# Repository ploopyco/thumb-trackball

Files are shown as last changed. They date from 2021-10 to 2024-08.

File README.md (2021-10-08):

# The Ploopy Thumb Trackball

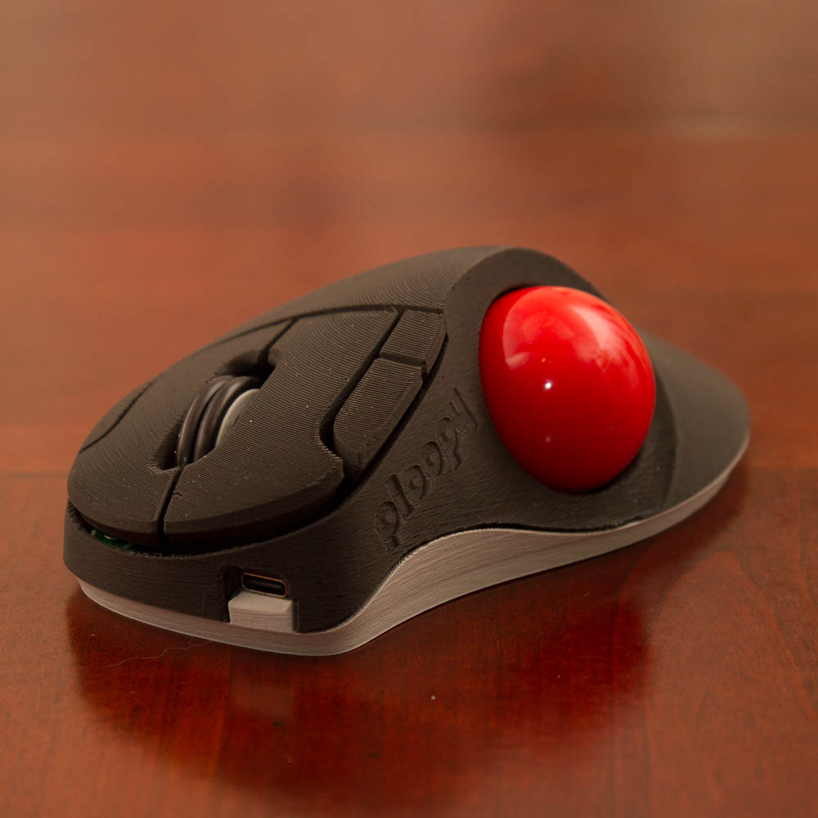
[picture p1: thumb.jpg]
The Ploopy Thumb Trackball


By some stroke of luck, you've made your way here. The Ploopy Thumb Trackball. Your life will never be the same.

This repository contains all of the design and production files necessary to make a Ploopy Thumb Trackball. We've also included some kick-ass documentation in the Wiki on how to get it made, assemble it, and program it.

What are you waiting for? Your new life awaits.

## QMK?!

Kits bought from the [Ploopy store](https://ploopy.co/product-category/trackball/thumb/) come with QMK preloaded. Check out the Wiki for instructions on how to load new firmware onto your device. (It's super easy!)

The firmware hex file that ships with all Nanos is included in this repository as well, as `ploopyco_trackball_thumb_rev1_001_via.hex`.

## Under what license is this released?

As per QMK's licensing requirements, the firmware for the Ploopy Thumb Trackball is released under GPLv3. Hardware design files, including electronics and mechanical files, are released under OHL CERN v2-S. Check the `LICENSE` file for full license text.

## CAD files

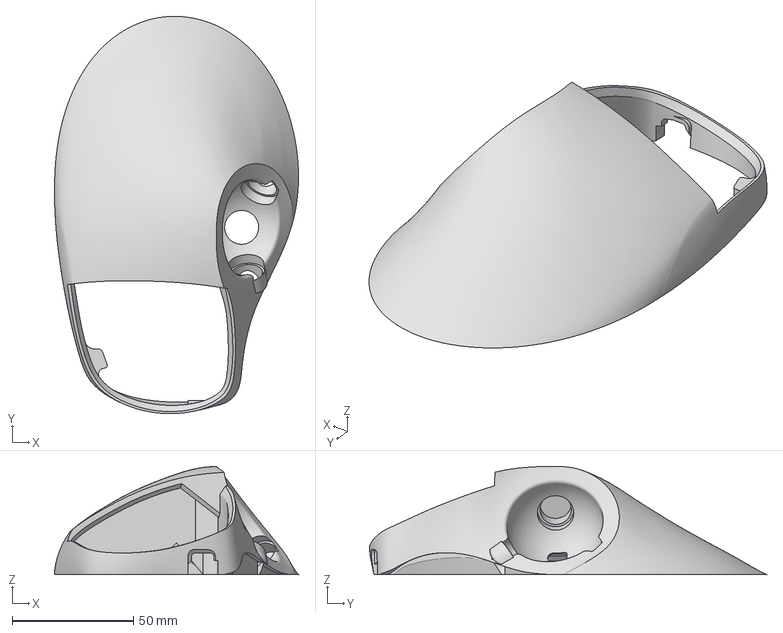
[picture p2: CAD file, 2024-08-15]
hardware/mechanicals-btu-mod/ploopy-thumb-btus-v1.3mf
100.7 x 164.0 x 44.7 mm

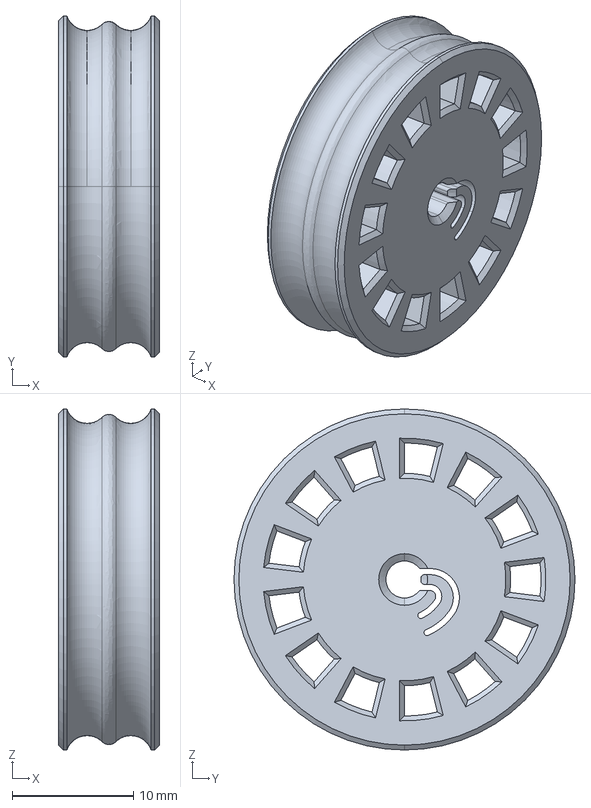
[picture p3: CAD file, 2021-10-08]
hardware/mechanicals/STEPs/ScrollWheel.STEP
8.30 x 28.1 x 28.1 mm

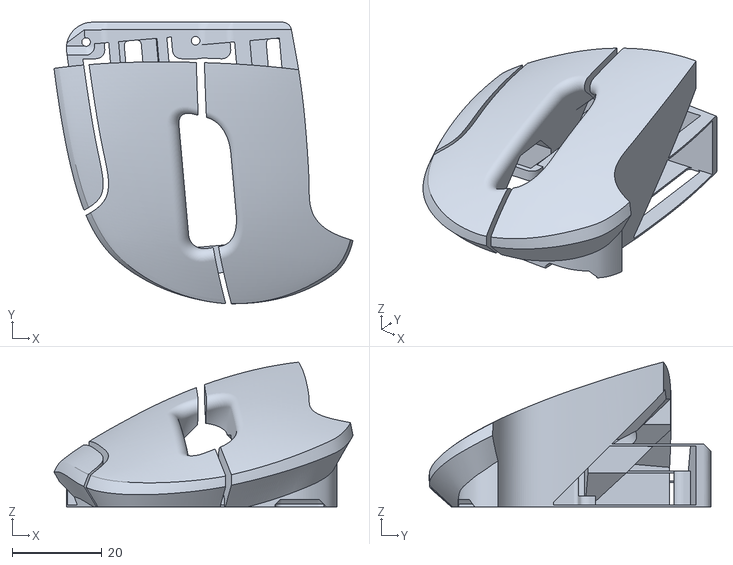
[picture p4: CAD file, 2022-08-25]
hardware/mechanicals/STLs/BigButtons.STL
66.6 x 62.7 x 32.3

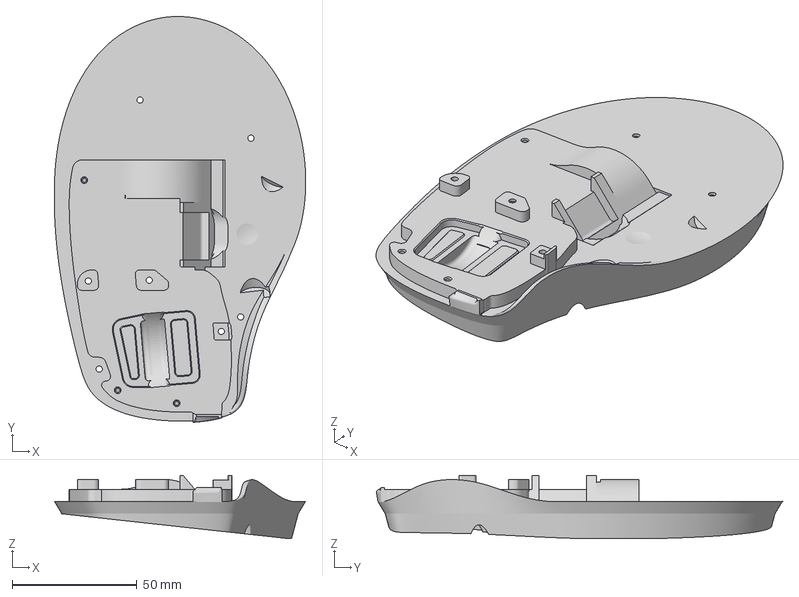
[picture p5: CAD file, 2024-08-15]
hardware/mechanicals-btu-mod/thumb-btu-base.3mf
100.7 x 162.6 x 25.4 mm

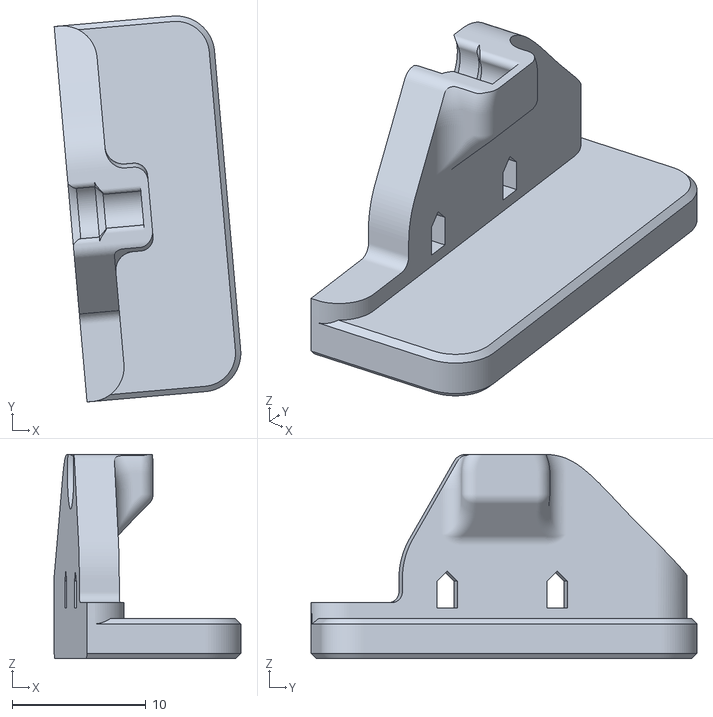
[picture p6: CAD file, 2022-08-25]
hardware/mechanicals/STLs/ScrollWheelFixedMount.STL
14.0 x 28.9 x 15.3

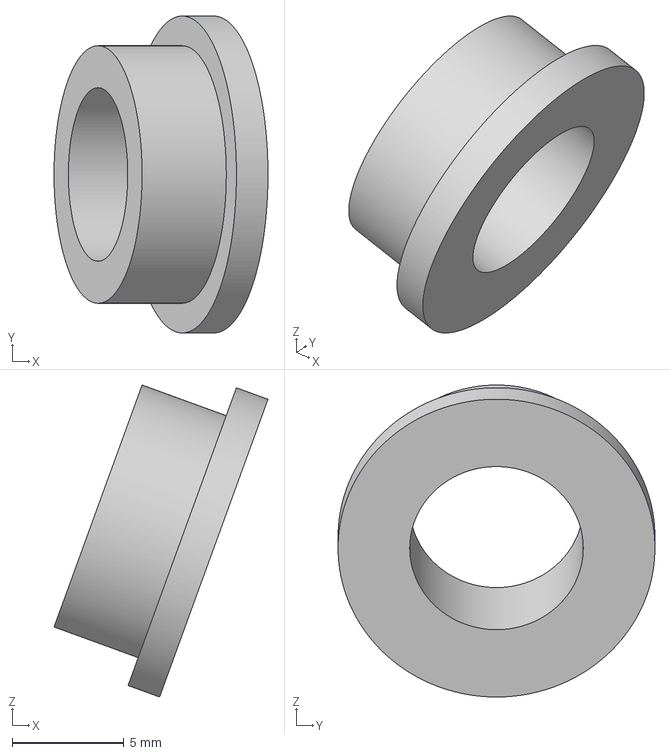
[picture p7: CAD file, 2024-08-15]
hardware/mechanicals-btu-mod/btu-sleeve.3mf
9.55 x 14.1 x 13.9 mm

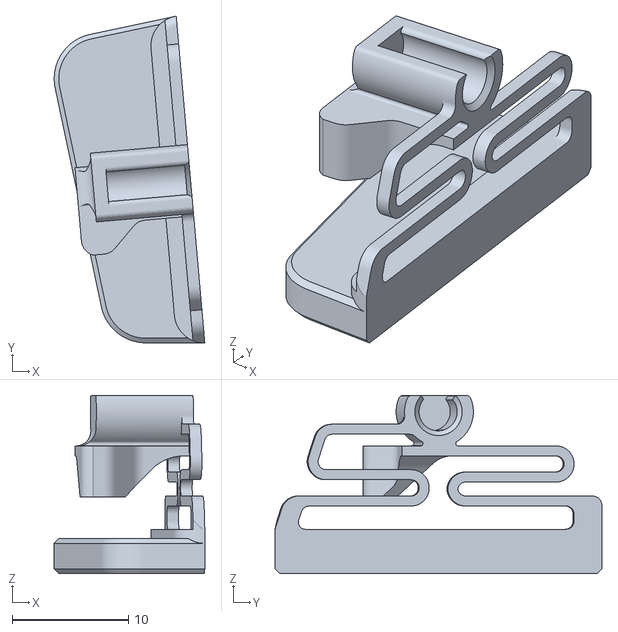
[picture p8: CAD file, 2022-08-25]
hardware/mechanicals/STLs/ScrollWheelSpring.STL
12.9 x 28.1 x 15.3

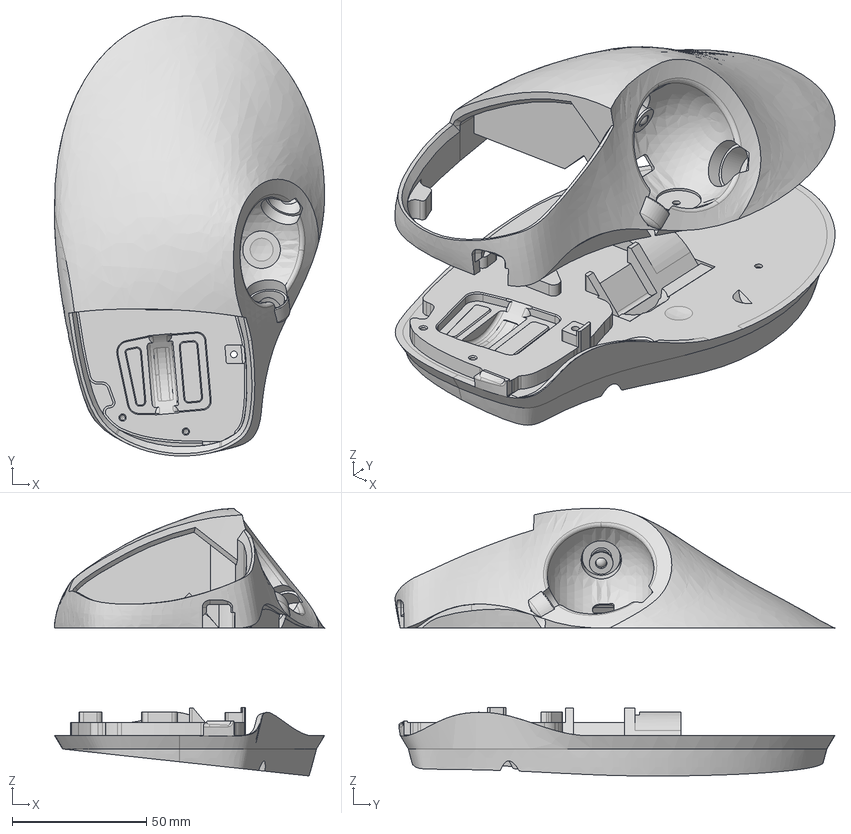
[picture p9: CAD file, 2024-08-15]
hardware/mechanicals-btu-mod/ThumbBodyParts-BTU v12.step
100.8 x 164.0 x 99.7 mm
BTU
btusleeve

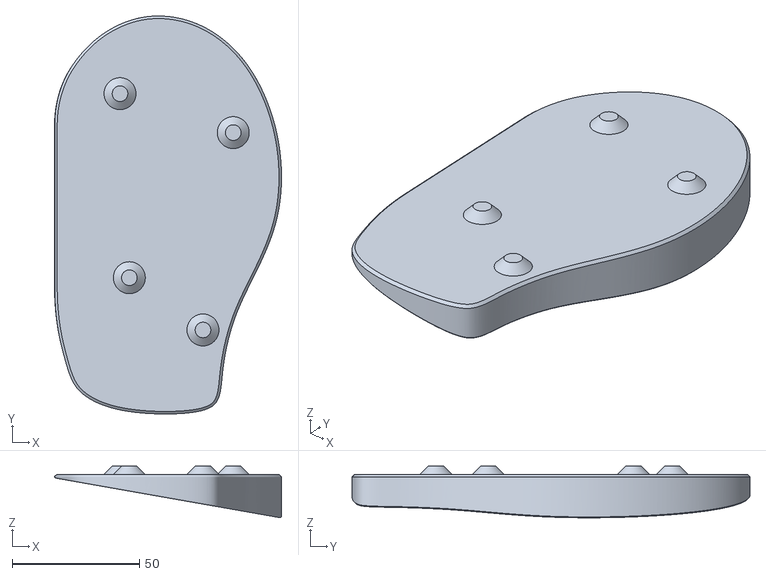
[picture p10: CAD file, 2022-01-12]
hardware/mechanicals/STLs/Wedge.STL
89.1 x 156.1 x 20.2

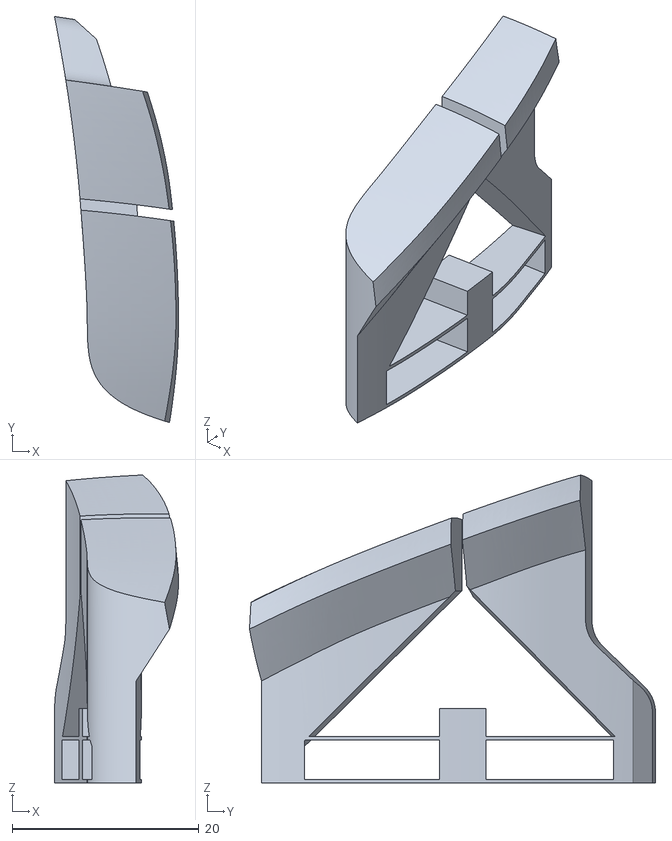
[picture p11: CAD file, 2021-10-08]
hardware/mechanicals/STLs/LittleButtons.STL
13.3 x 43.5 x 33.0

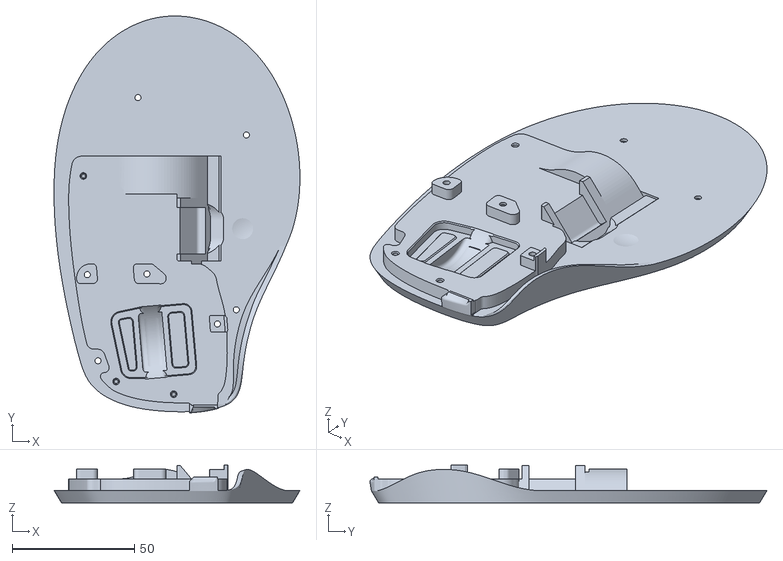
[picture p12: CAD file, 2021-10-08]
hardware/mechanicals/STLs/Bottom-NoLogo.STL
100.7 x 162.6 x 15.4

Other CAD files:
hardware/mechanicals/STLs/Top-NoLogo.STL
hardware/mechanicals/STLs/ScrollWheel.stl

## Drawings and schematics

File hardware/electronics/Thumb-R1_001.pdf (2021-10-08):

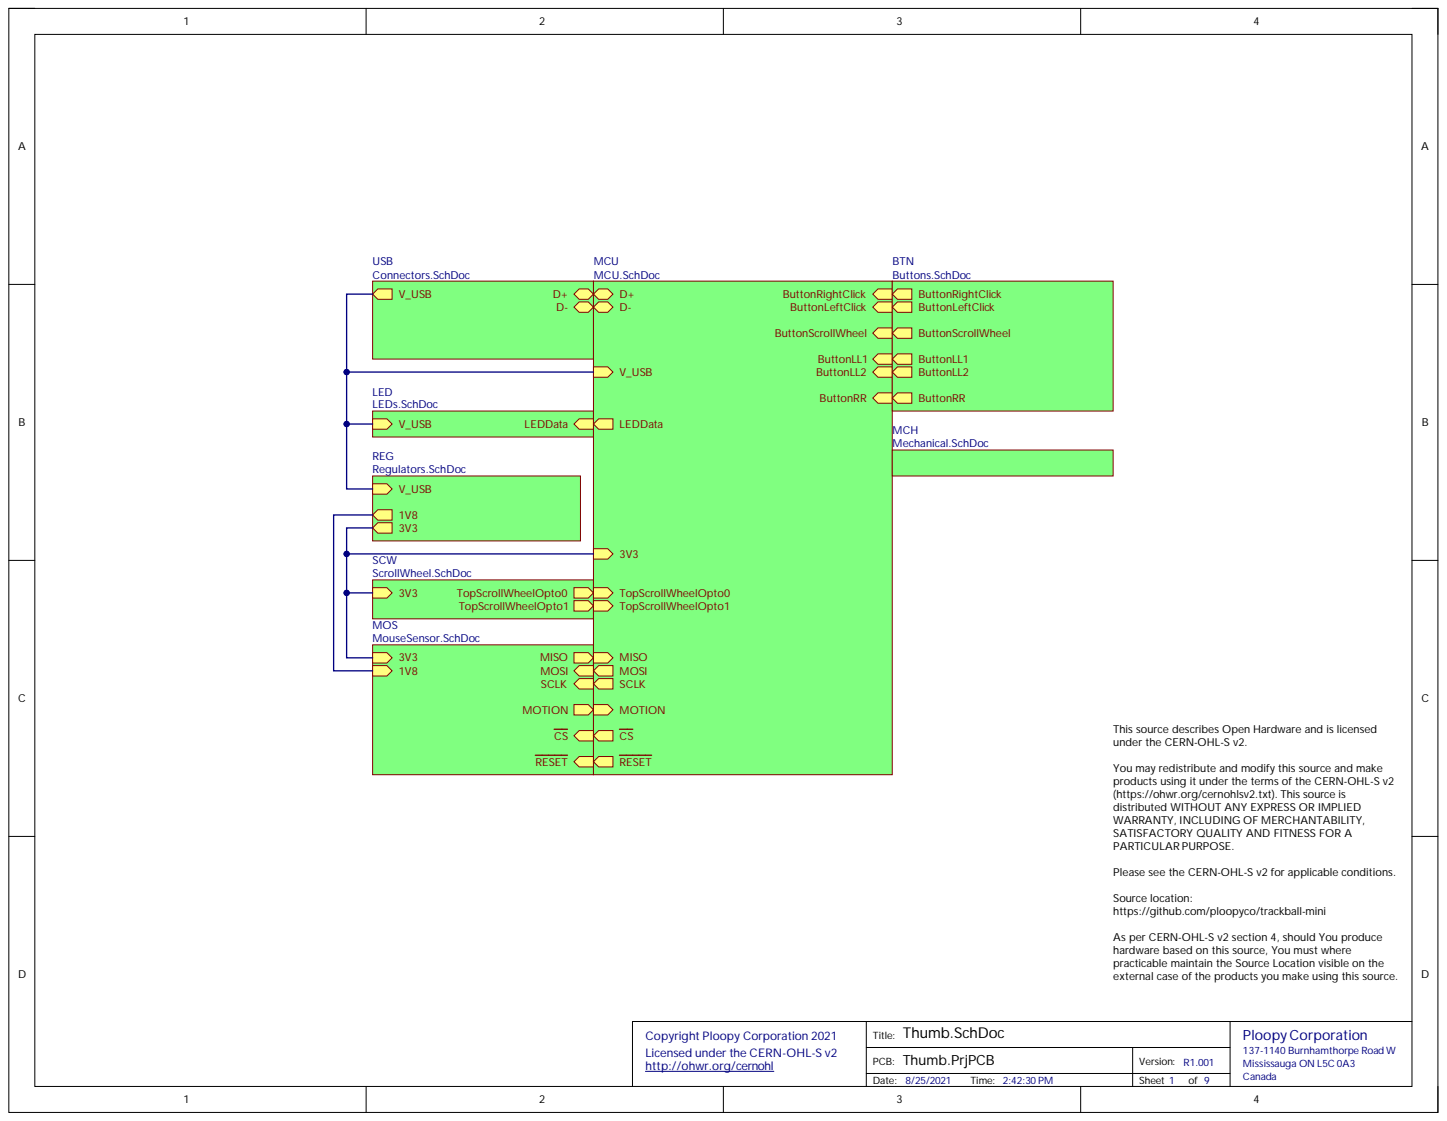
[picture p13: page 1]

This source describes Open Hardware and is licensed
under the CERN-OHL-S v2.

You may redistribute and modify this source and make
products using it under the terms of the CERN-OHL-S v2
(https://ohwr.org/cernohlsv2.txt). This source is
distributed WITHOUT ANY EXPRESS OR IMPLIED
WARRANTY, INCLUDING OF MERCHANTABILITY,
SATISFACTORY QUALITY AND FITNESS FOR A
PARTICULAR PURPOSE.

Please see the CERN-OHL-S v2 for applicable conditions.

Source location:
https://github.com/ploopyco/trackball-mini

As per CERN-OHL-S v2 section 4, should You produce
hardware based on this source, You must where
practicable maintain the Source Location visible on the
external case of the products you make using this source.

Copyright Ploopy Corporation 2021
Licensed under the CERN-OHL-S v2
http://ohwr.org/cernohl

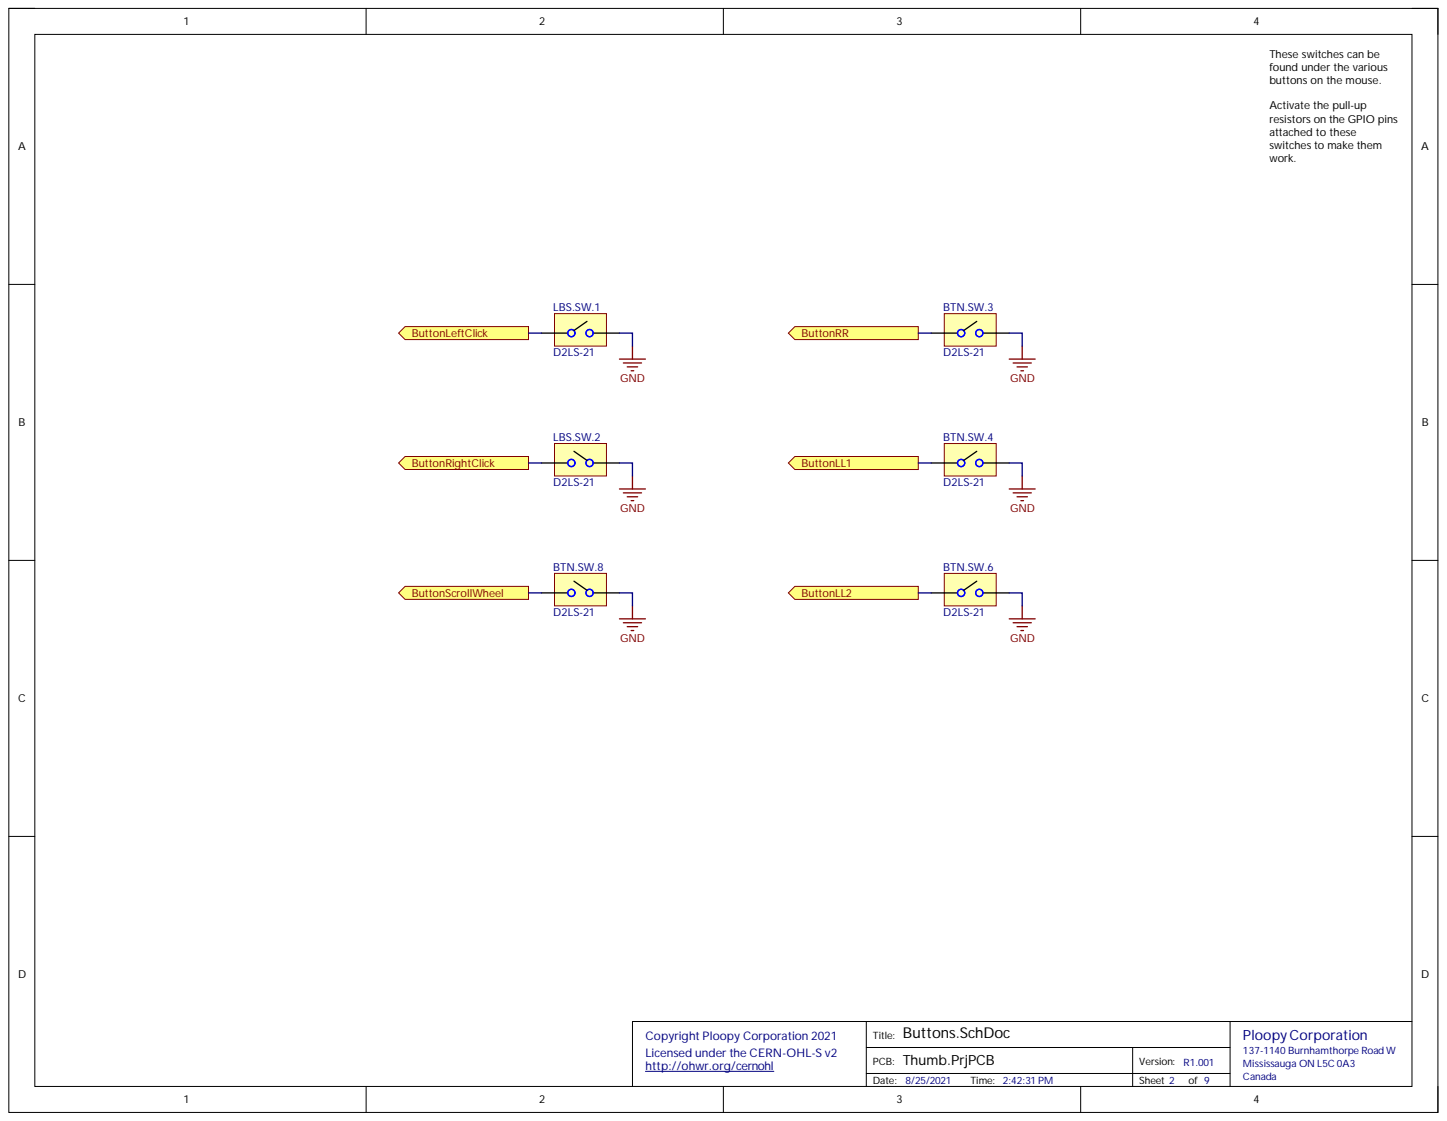
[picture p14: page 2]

These switches can be
found under the various
buttons on the mouse.

Activate the pull-up
resistors on the GPIO pins
attached to these
switches to make them
work.

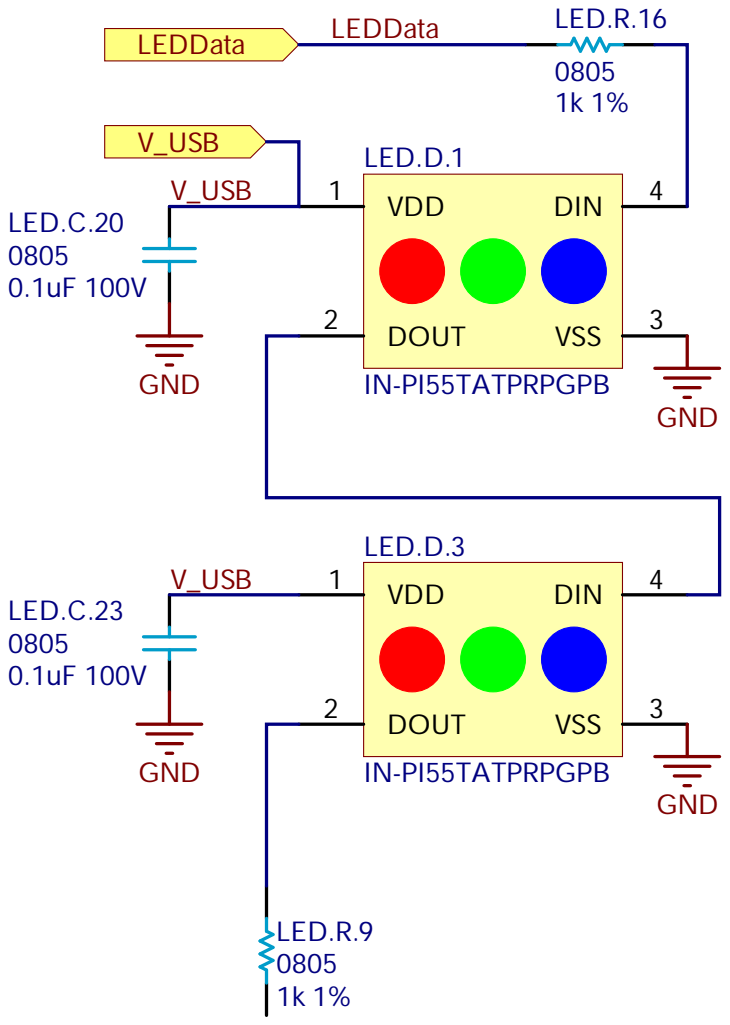
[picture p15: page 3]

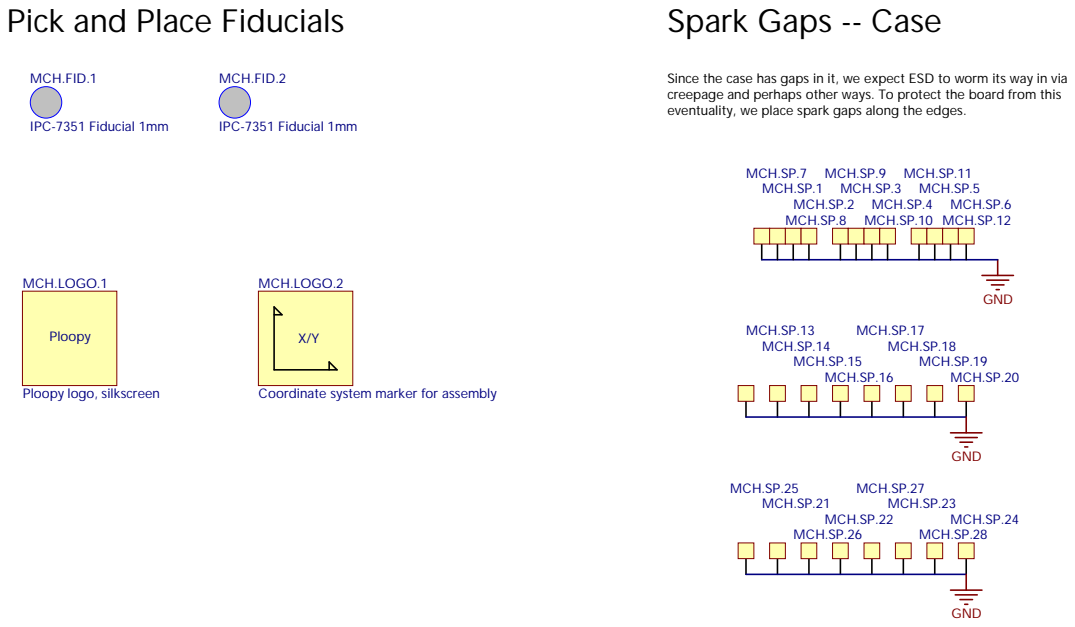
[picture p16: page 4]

Pick and Place Fiducials

Spark Gaps -- Case MCH.SP.7 MCH.SP.1 MCH.SP.8 MCH.SP.2 MCH.SP.9 MCH.SP.3 MCH.SP.10 MCH.SP.4 MCH.SP.1

Since the case has gap
creepage and perhap
eventuality, we place s

s other ways. To protect the board from this
park gap

pect ESD to worm its way in via

Coordinate system marker for assem

Cop
Licensed under the CE
http

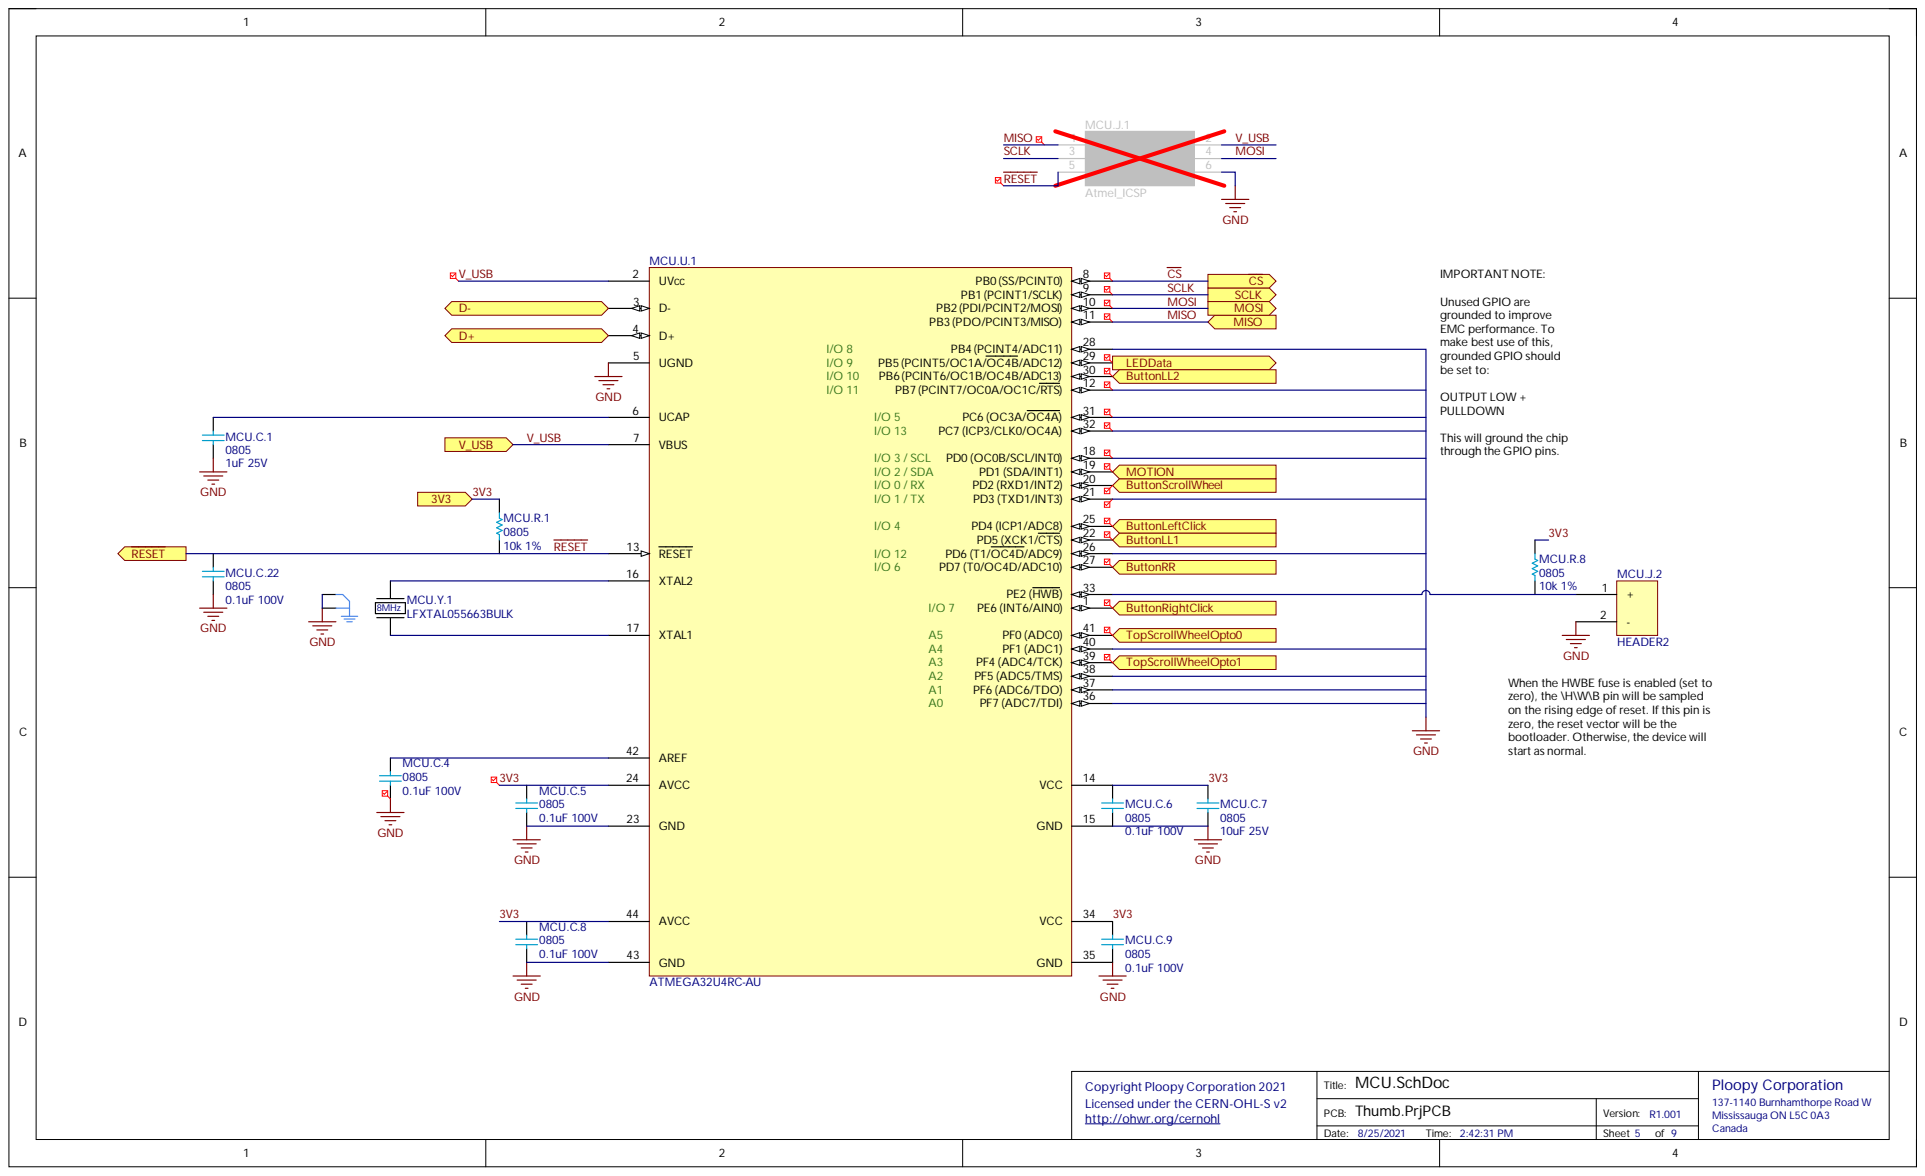
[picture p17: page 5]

performance.
best use of thi
GPI

C opy righ t Plo opy C o rpo ratio n 2 0 2 1 Lice n sed u nde r t h e CERN -O HL-S v 2 h t tp://o hwr.o rg/ce r n o h l | T i t le: MCU.SchDo c | Ploop y Corporation 137-1140 Burnha m tho rpe Ro ad W M i ss i ssauga ON L5C 0A 3 C anada

Thum b.PrjPC B P C B : | Vers i o n : R1.001

D a te: 8/25/2021 T i me: 2:42:31 P M | Sheet 5 o f 9

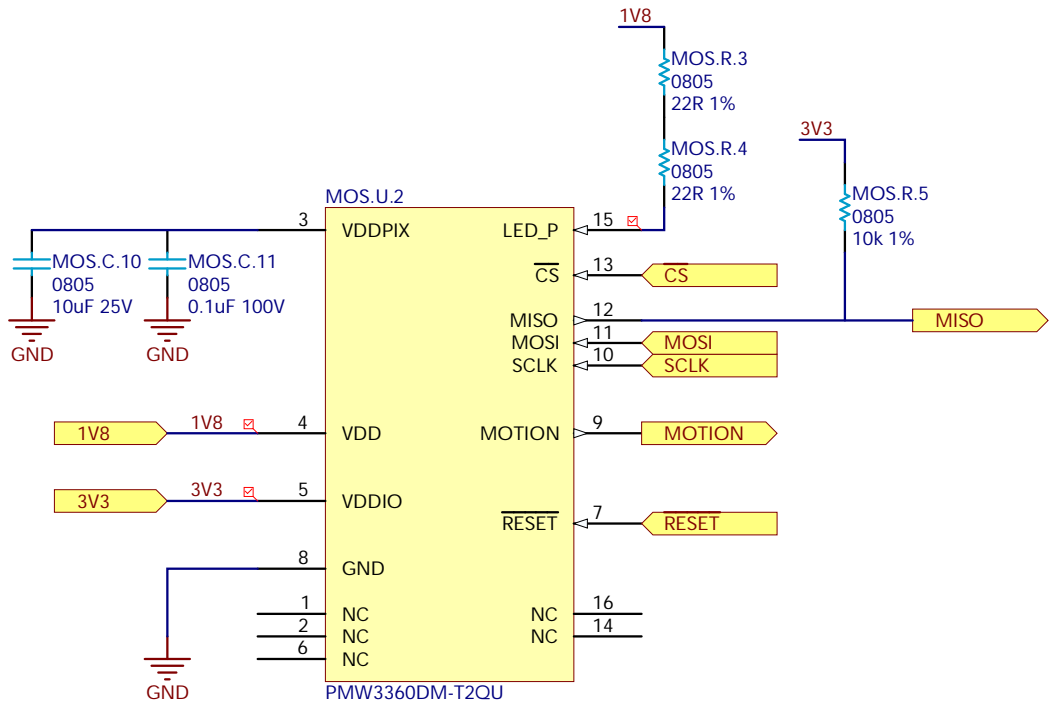
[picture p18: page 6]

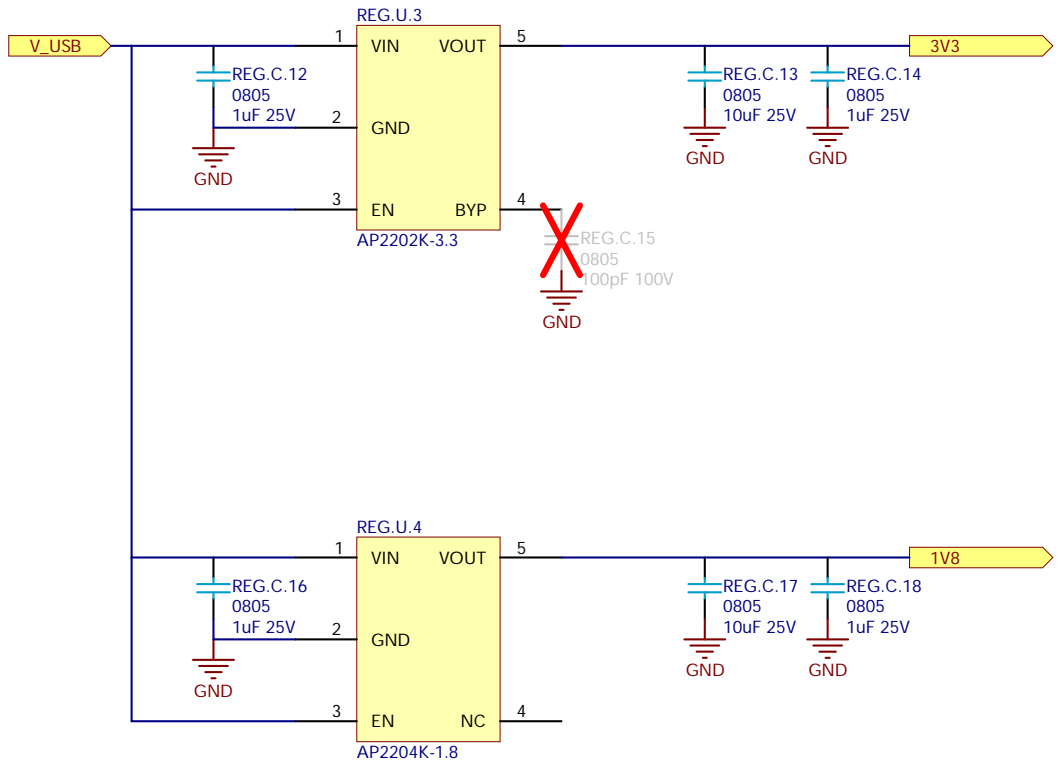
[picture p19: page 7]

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
## Ploopy

## Corporati

o

n

Mississauga ON

L5C 0A3

Sc

## rollWheel.SchDoc

R1.

8/25/202

1 | 2:42:31

P

M

Titl

e

:

Date

:

Versi

o

n

:

Ti

m

e

: | She e

t

o

f

PCB

:

## Thumb.Prj

P

C

B

Cop

yri

ght Ploop

y Corporation 2021
137-1140

Burnhamthorpe Ro

ad

W

Cana

d

a

Licensed under the CE

R

N

OHL-S

v
http

:

//ohwr.org

/ce

r

n

o

h

l

# TopScrollWheelOpto0 TopScrollWheelOpto1

SCW.Qt.

1
PT26-51B/T

R8 or PT12-21B/T

R

8

SCW.Qt.

2
PT26-51B/T

R8 or PT12-21B/T

R

8

The scroll wheel mechanis

m is a 2-

bit optical
encoder. The light paths are s

paced 1.5
period

s over the encoder wheel holes, which should allow for the detection of the rotation direction as well as the rotation itself. Two IR LEDs are used as light sources; the light

from these is ob

structed by the encoder wheel built into the scroll wheel mechanis

m. T

wo
phototransistors are used to

detect

when the
light is blocked/not blocked by the wheel. Typical LED forward voltage is 1.3V @20m

A.
To achieve this current level with a 3.3V sup

ply,
we'll use a 100R resistor, which is very convenient. At this power level, the output should be

ap

prox 2.3mW/sr.

Since the light path distance is about 12m

m,
that work

s out to about 2mW/cm

^2, though
the actual delivered power will be lower due to the vagaries of the ob

structions in the
mechanis

m

With this amount of light (and accounting for the fact that we'll probably lose a lot of it along the way), we are ex
pecting 1-3m

A out of
the phototransistor (see figure 6 of the datasheet), so we size the biasing resistor

accordingly to produce a useful signal.

100R 1%

SCW.R.1
0805

100R 1%

SCW.R.3
0805

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
1k 1%

SCW.R.2
0805

1k 1%

SCW.R.4
0805

G

N

D

3V

3

SCW.D.1

1
I

R12-21C/T

R8 or VSM

B10940

SCW.D.1

2
I

R12-21C/T

R8 or VSM

B10940

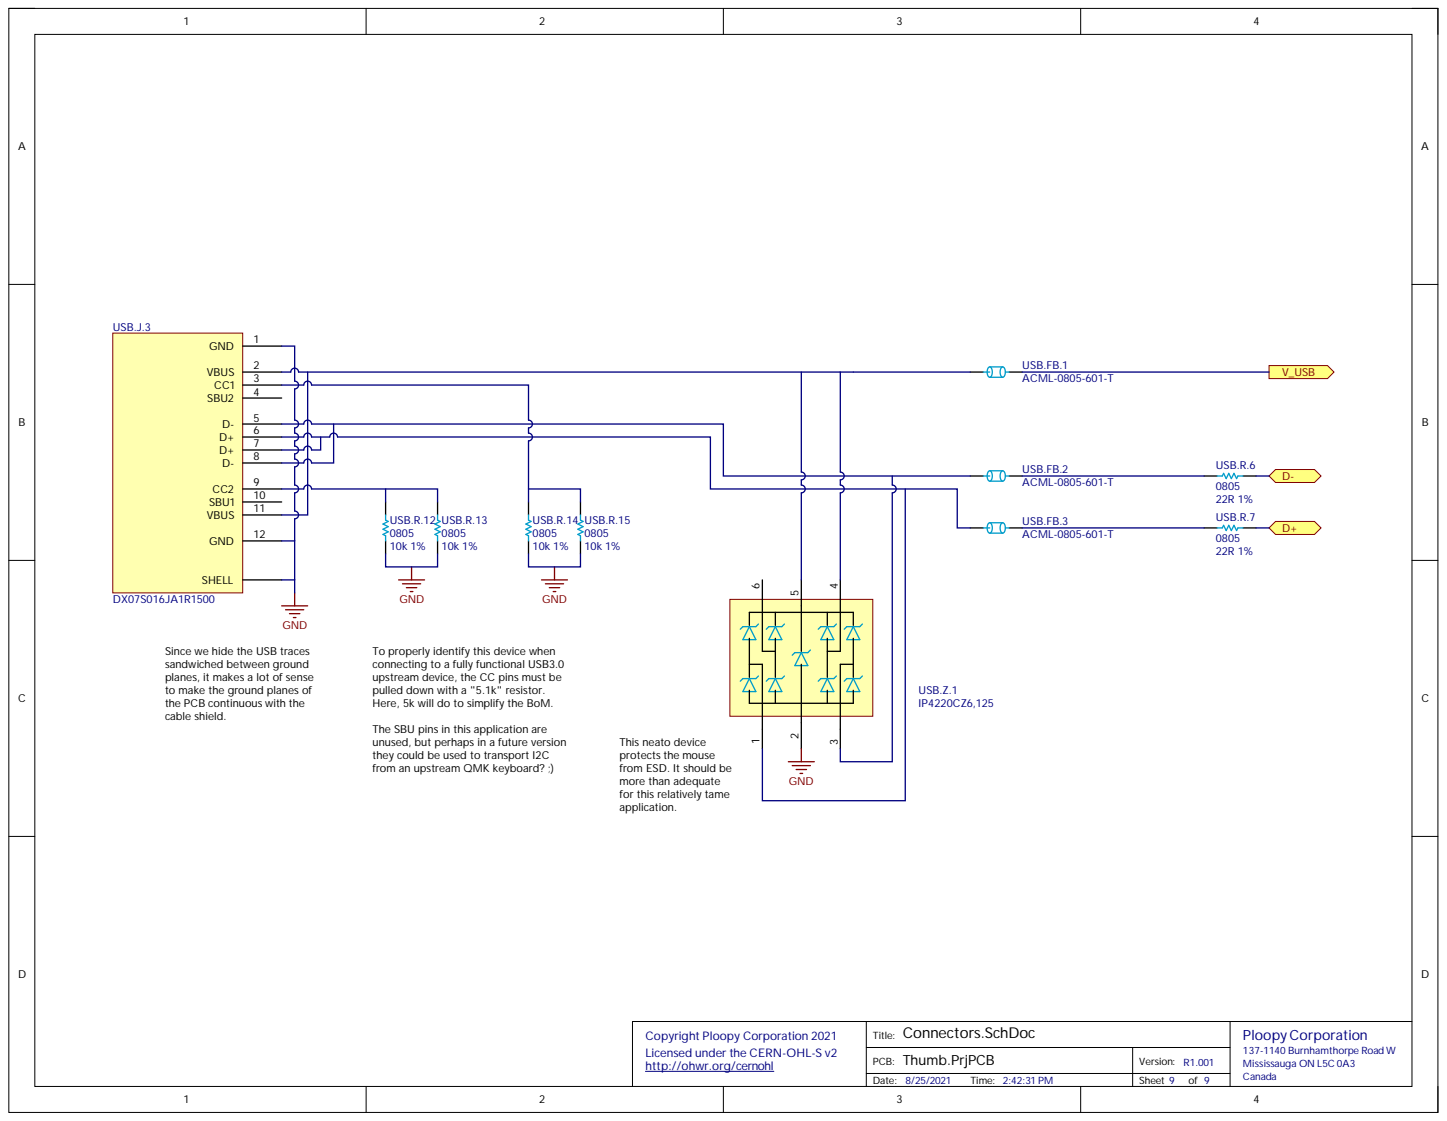
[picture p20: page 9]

Since we hide the USB traces sandwiched between ground planes, it makes a lot of sense

To properly identify this device when
connecting to a fully functional USB3.0
pulled down with a "5.1k" resistor.
Here, 5k will do to sim

to make the ground planes of
the PC
cable shield

The SB
unused, but perhap
they could be used to trans
from an up

U pins in this ap

This neato device protects the mouse

from ESD. It should be more than adequate

for this relatively tame

Cop
Licensed under the CE
http

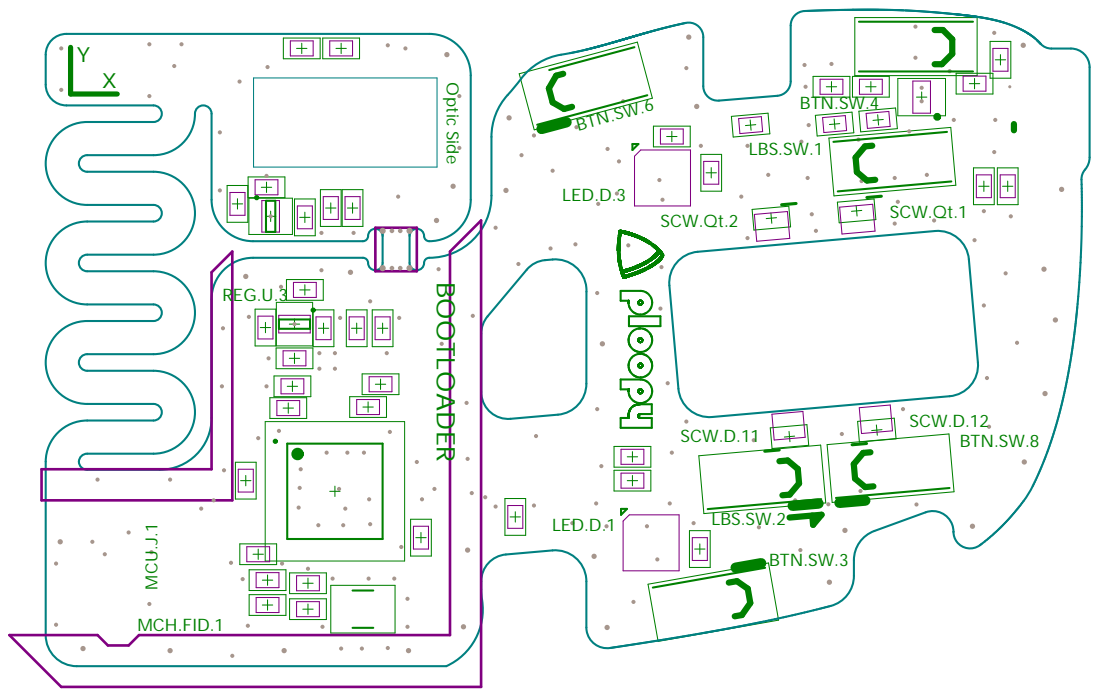
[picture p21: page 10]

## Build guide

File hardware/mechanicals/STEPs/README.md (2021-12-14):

## What's the difference between the two Tops?

The "-200" body has its ball well offset by 200um. This is to accommodate variations in ball size.

If you're looking to replace the Top that you got from an official Ploopy kit, look at the underside of the Top that came in your kit. If it has small shallow circular divot, use the "-200" Top. If it doesn't, use the "-0" Top.

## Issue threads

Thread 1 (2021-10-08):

Include BOM and Gerber Files

mizz141, 2021-10-08:
Would it be possible to have a Bill of Materials and Gerber files available along with the propietary PCBLIB and SCHLIB files?

IBNobody, 2021-12-14:
@mizz141 You can generate these yourself for FREE by uploading the design into Altium365, provided free via Altium's circuitmaker app.

[Thumb-R1_001_gerber.zip](https://github.com/ploopyco/thumb-trackball/files/7714505/Thumb-R1_001_gerber.zip)
[Thumb-R1_001_BOM.csv](https://github.com/ploopyco/thumb-trackball/files/7714506/Thumb-R1_001_BOM.csv)

This is just the electrical BOM, by the way.

@ploopyco You can put these in the repo if you want, but I would recommend that you generate them yourself.

Closed 2024-04-08.

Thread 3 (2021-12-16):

Scroll Wheel Can Spin Faster than the Sensors Can Detect

IBNobody, 2021-12-16:
Because the scroll wheel does not have a clicking mechanism similar to other mice/trackballs, the wheel can spin and coast freely. This feels fine from an ergonomic standpoint, but I noticed issues with the scroll wheel sensor.

When I spin and coast the wheel, the IR LED / phototransistor combo first detect that the wheel is spinning in the opposite direction. It then stops scrolling, and finally it begins scrolling in the correct direction.

Probably a similar effect to this... https://www.youtube.com/watch?v=VNftf5qLpiA

I suspect this is due to whatever sampling rate QMK was set up to sample the phototransistors. I saw that the code has a debounce time of 5ms, which (if the sampling rate of the wheel is handled by a counter) would be about 200Hz. Could this be dropped to 2 or 3?

kevinlekiller, 2022-01-20:
Noticing this as well, figured it was because of the small pieces of filament wire I couldn't get rid of inside the encoder, but your theory makes more sense.

mfish38, 2023-09-18:
Looking at the QMK source code, I believe that this is due to debounce logic on the scroll wheel. It looks like by default scroll events are ignored if they occur within 5 ms of a previous event.

I tried reducing the debounce time and it seemed to improve the issue without introducing any issues. To do this in your QMK keymap folder create a "config.h" if does not exist and add:

```h
#define OPT_DEBOUNCE 1  // (ms)
```

You can try 0 to disable the debounce completely, but I suspect that this might cause issues if there is any noise.

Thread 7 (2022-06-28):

Wedge 'nubs' too large for Trackball Base Holes

Reconfirefly, 2022-06-28:
Forgive me if I'm just missing the forest for the trees here, but is there a reason that the four "frustums" on the top of the wedge are oversized compared to the holes they mate with on the bottom of the Ploopy? The wedge-wedge connection is solid, as the surfaces lay flush against one another, but the ploopy bottom sits ~1mm above the wedge suface due to the size mismatch.

nburns, 2022-10-21:
I have the pads installed on the bottom of my mouse and on a wedge, and they mate "correctly" which I think explains their larger size. i.e. with no pads they would be oversized, but with pads they would not engage

chrisistansell, 2022-11-01:
I personally have a tip and it splits open issue.  When it happened to me, kind of gave the rocking in my hand feeling. In my case I took the pads off and put a moderately thin clear double-sided tape between them to stop it from happening.  1/2" (12.7mm) 0.85mm thick tape.

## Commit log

2021-10-08 initial release
    Update README.md
    Update README.md
    removed logoed versions of stls
    [BigButtons.STL, Bottom-NoLogo.STL, Buttons.SchDoc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]
2021-12-14 updated scroll wheel spring
    [ScrollWheelSpring.STL, Top-NoLogo.STL]
2022-01-05 added scroll wheel
    [ScrollWheel.stl]
2022-01-12 added wedge stl
    [Wedge.STL]
2022-08-25 fixed scroll wheel
    [BigButtons.STL, ScrollWheelFixedMount.STL, ScrollWheelSpring.STL]
2024-08-15 add files for thumb btu mod
    [ThumbBodyParts-BTU v12.step, btu-sleeve.3mf, ploopy-thumb-btus-v1.3mf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]
